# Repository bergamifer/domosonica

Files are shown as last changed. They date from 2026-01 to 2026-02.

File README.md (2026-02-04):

# Domosonica - WiFi Audio Streaming Board

## Project Overview

Domosonica is an experimental sound spatialization project that aims to create an accessible platform for the creation and immersive listening of spatialized audio, offering a multidirectional acoustic experience. Unlike traditional approaches that often involve expensive technologies and are confined to exclusive cultural settings, Domosonica takes an inclusive approach by leveraging recycled or low-cost technological resources.

This repository contains the design files for the WiFi-enabled audio streaming board, the core electronic component of the Domosonica project.

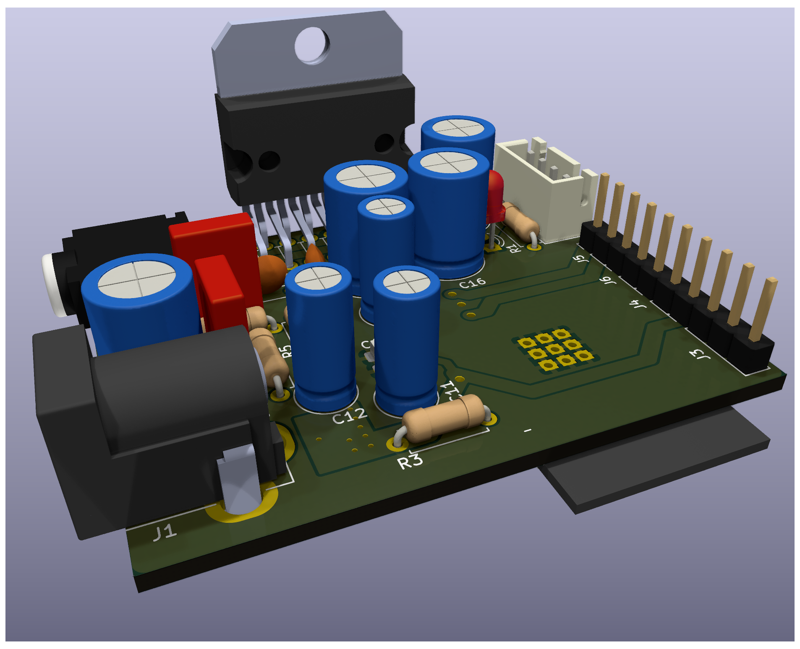
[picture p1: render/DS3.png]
Board Render


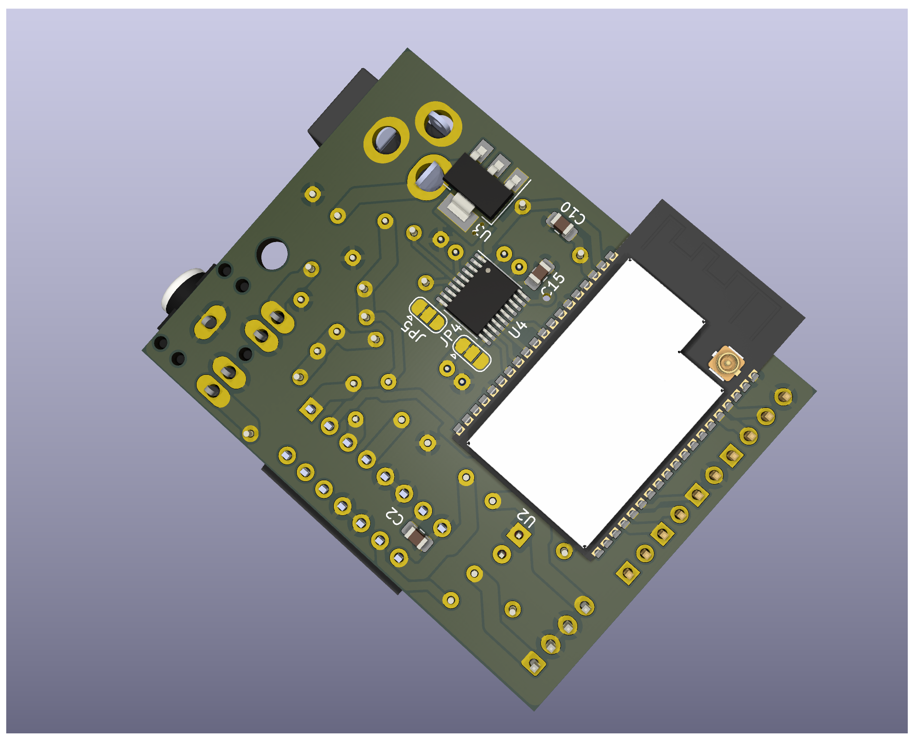
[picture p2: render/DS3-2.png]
Board Render Alternative View


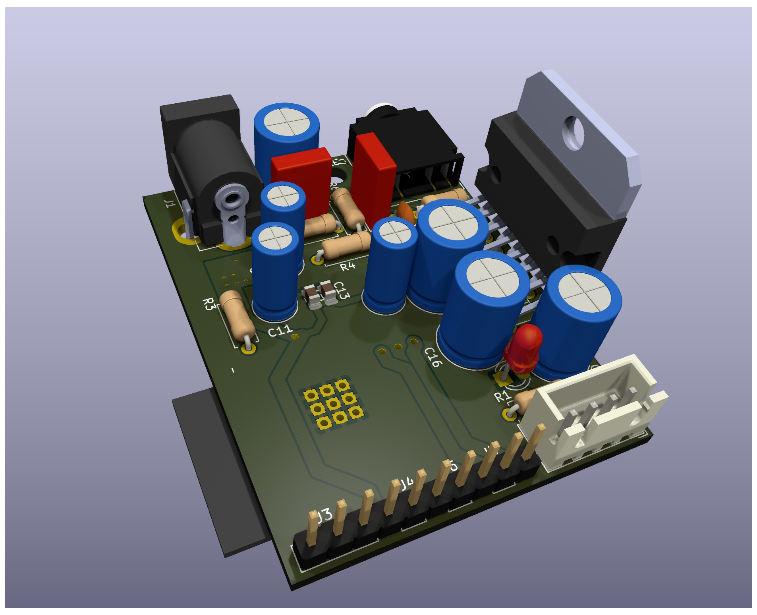
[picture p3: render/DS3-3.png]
Board Render Alternative View


## Key Features

- **Inclusive Access**: Designed to break down barriers, making spatialized audio accessible to a wide range of creators, artists, students, and educators.
- **Community Interaction**: Fosters social connections and collaboration between diverse stakeholders in the arts and the local community.
- **Democratizing Sound Art**: By embracing low-cost and recycled technologies, Domosonica democratizes technological sound art, making it available to a broader audience.
- **Cultural Enrichment**: Contributes significantly to the cultural landscape of Parque de Los Patricios, aligning with the identity of the Technology District of Buenos Aires.

## Technical Specifications

### Hardware Components

1. **ESP32 Microcontroller**: A powerful microcontroller with Wi-Fi and Bluetooth capabilities, serving as the heart of the project. It handles internet connectivity, file storage, and audio output.

2. **TDA7496 Stereo Amplifier**: Each board includes a stereo amplifier capable of driving a pair of speakers directly.

3. **SPIFFS (Serial Peripheral Interface Flash File System)**: An onboard file system used by the ESP32 for storing files, useful for caching audio content.

4. **I2S Digital Audio Interface**: A communication protocol specifically designed for digital audio. The ESP32's I2S interface connects to the internal DAC for audio output.

5. **Recycled Speakers**: The system uses speakers salvaged from old televisions, mounted in custom 3D-printed enclosures.

### Circuitry

- **I2S Pins**: The ESP32 is connected to the DAC using specific pins dedicated to I2S communication. These pins transmit the clock signals and the audio data.
- **Power Supply**: The ESP32 and the audio output devices require a stable power supply. USB power or a regulated power adapter can be used.
- **Stereo Output**: Each board drives two speakers independently for stereo sound reproduction.

### Software Components

- **WiFi Library**: For connecting the ESP32 to the internet via Wi-Fi.
- **HTTPClient Library**: For handling HTTP requests to download audio files.
- **SPIFFS Library**: For interfacing with the ESP32's onboard file system.
- **AudioTools Library**: A comprehensive library for audio playback, including support for various audio formats and protocols, including MP3 decoding and I2S.
- **AudioLibs and AudioCodecs**: Additional libraries that provide specific functionality, such as interfacing with the SPIFFS and decoding audio files.

### Setup and Configuration

- Wi-Fi credentials and target URL for audio streams are specified in the firmware.
- I2S and audio playback settings are configured to match the capabilities of the ESP32 and the connected audio hardware.

### Usage

Once the system is powered and the firmware is running:
1. The ESP32 connects to the specified Wi-Fi network.
2. It receives audio streams from the network.
3. Audio playback occurs automatically using the I2S protocol through the TDA7496 amplifier.

## The Dome Installation

The geodesic dome measures 4 meters in diameter and is suspended from the ceiling of "Circo" at CheLA. The structure is held by 5 attachment points (carabiners), keeping the space below free for visitors to explore its interior from a sonic perspective.

### Speaker Design

30 custom enclosures were designed and 3D printed, each housing a recycled television speaker. These speakers were mounted at the nodes of the geodesic dome structure and connected in pairs to each streaming board.

### Board Manufacturing

The PCB was designed from scratch using KiCad (open-source software). The boards were manufactured in China and then hand-soldered at the Pedalúdico workshop at CheLA.

## Location

**CheLA (Centro Hipermediático Experimental Latinoamericano)** is a cultural center located in Buenos Aires, Argentina. It is known for its focus on experimental and multimedia arts, technology, and cultural activities. CheLA provides a space for artists, creators, and researchers to explore various forms of art and technology.

## Educational Workshops

The project included a series of workshops:

- **Amplifier Building Workshops**: A series of 3 workshops (15 participants each) where young people built amplifiers using recycled TV speakers. Participants took home their own amplifiers to connect to their phones and listen to music.

- **FADU (UBA) Collaborations**: Practical sessions were conducted with design students from the Faculty of Architecture, Design and Urbanism at the University of Buenos Aires.

- **Community Building**: Neighborhood residents from Barracas participated in the construction of the dome, which was assembled using PVC pipes shaped with a heat gun.

## Final Conclusions

### Technical Learnings

The ESP32 microcontroller, while powerful and cost-effective, proved to have limitations when processing large volumes of audio signals simultaneously. The board was designed with only **two stereo channels** per unit, which initially seemed limiting for an immersive audio installation.

### Scaling the Solution

To overcome the channel limitation, we manufactured **20 boards in total**, resulting in **40 independent audio channels** distributed throughout the dome. While achieving perfect synchronization across all WiFi-connected units presented challenges, we managed to obtain sufficient synchronization to create compelling surround sound effects.

### Artistic Results

The system enabled some truly **interesting surround sound experiments** inside the dome. The ability to independently control each speaker pair over the local network opened creative possibilities for spatial audio compositions and performances.

### Future Potential

The dome has significant untapped potential. Our vision is to develop a platform that would allow artists from around the world to simultaneously stream their instruments to each speaker independently, creating a new paradigm for collaborative spatial audio performances.

## Safety Notes

- Ensure the power supply is within the acceptable range for the ESP32 and other components to avoid damage.
- Be cautious with speaker volume to prevent hearing damage.
- Properly insulate all connections to prevent shorts.

## License

Domosonica is an open source project. Feel free to use, modify, and share it within the terms of the license.

## Contributing

We welcome contributions from artists, technologists, educators, and anyone interested in pushing the boundaries of sound art.

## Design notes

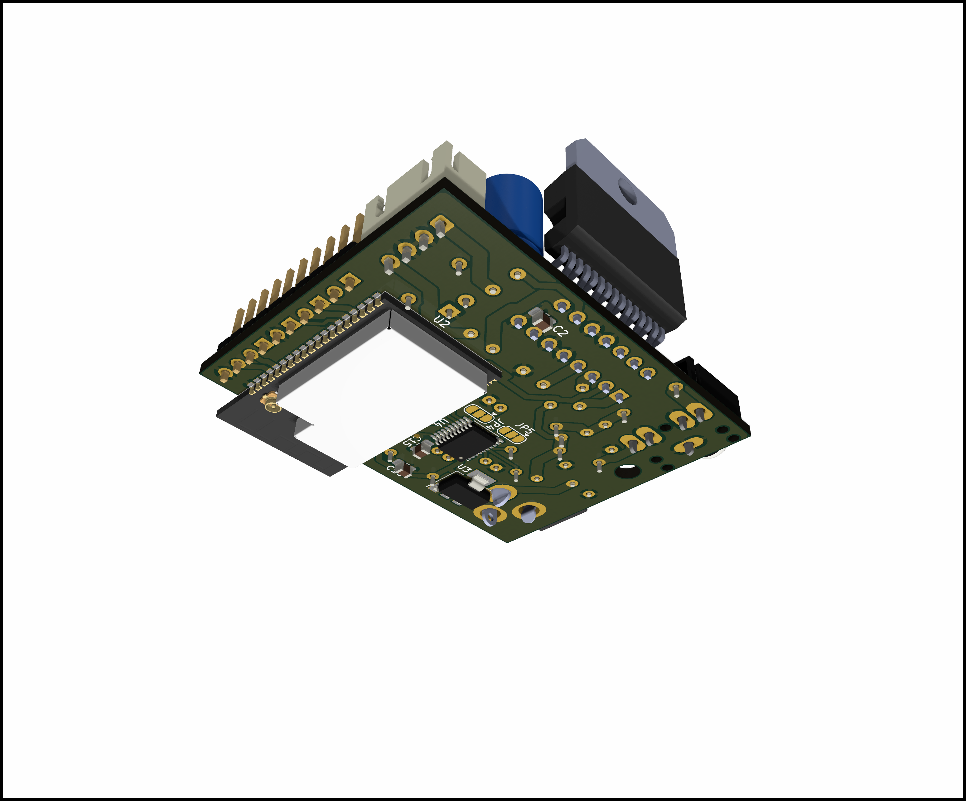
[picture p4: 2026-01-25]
render/Modulo-completo4(2).png

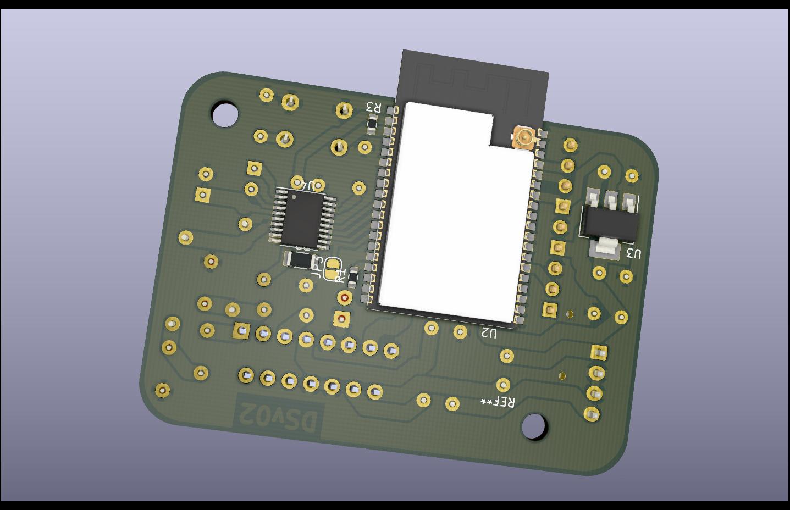
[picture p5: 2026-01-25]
render/Modulo-completo5.jpg

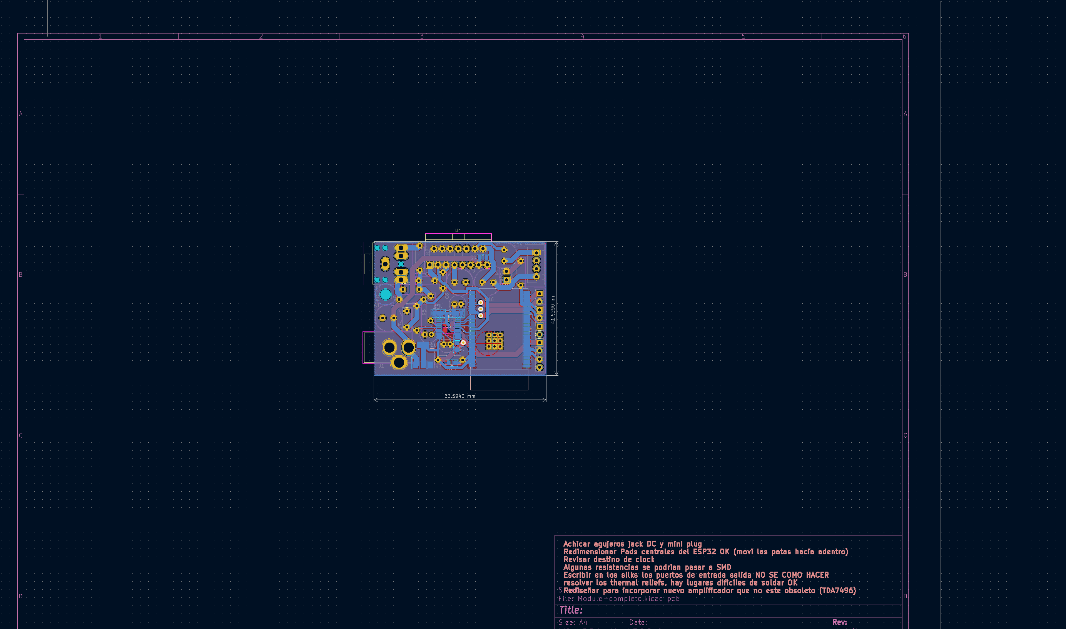
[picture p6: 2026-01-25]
render/Modulo-completo4.png

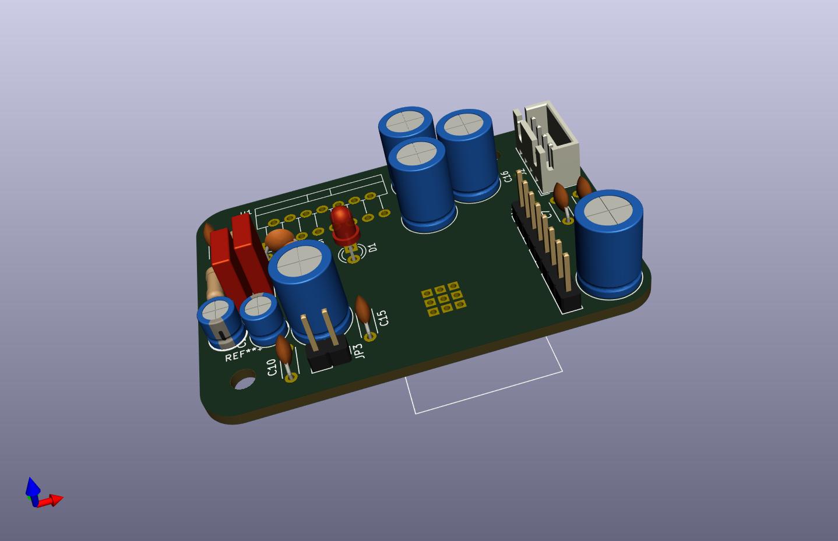
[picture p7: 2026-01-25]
render/Modulo-completo3.jpg

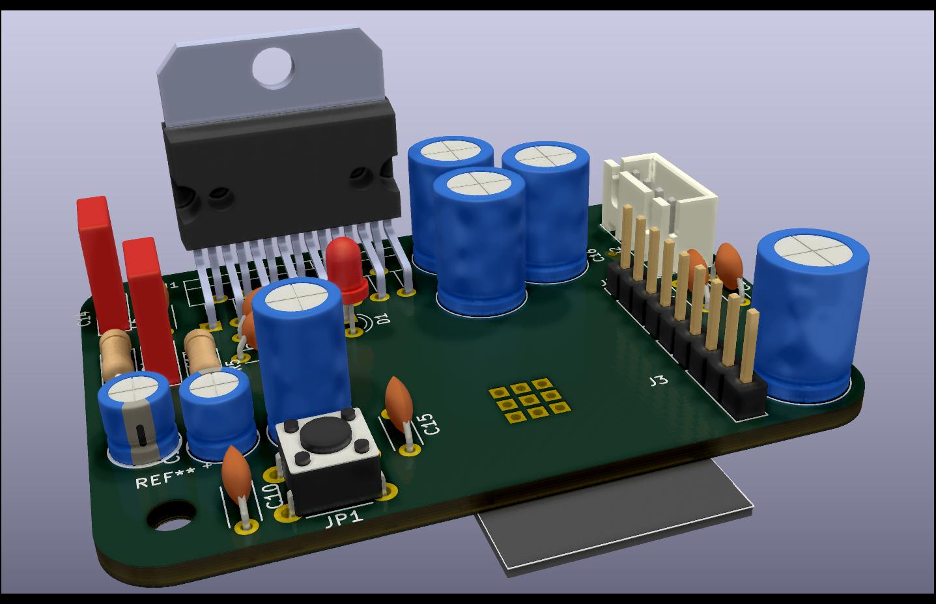
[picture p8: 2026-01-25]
render/Modulo-completo4.jpg

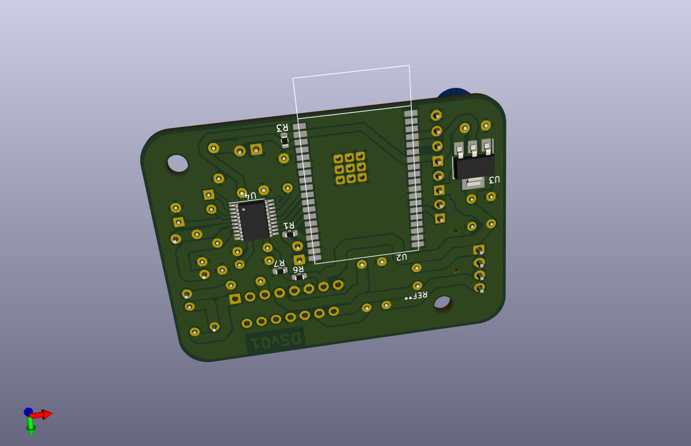
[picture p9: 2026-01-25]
render/Modulo-completo2.jpg

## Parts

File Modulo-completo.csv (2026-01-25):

Reference | Value | Footprint | Datasheet
U3 | AP1117-33 | Package_TO_SOT_SMD:SOT-223-3_TabPin2 | http://www.diodes.com/datasheets/AP1117.pdf
J1 | Conn_01x02 | Connector_PinHeader_2.54mm:PinHeader_1x02_P2.54mm_Vertical | ~
C2 | 100nF | Capacitor_THT:C_Disc_D6.0mm_W2.5mm_P5.00mm | ~
C1 | 1000uF | Capacitor_THT:CP_Radial_D8.0mm_P3.50mm | ~
C8 | 1000uF x 6.3v | Capacitor_THT:CP_Radial_D8.0mm_P3.50mm | ~
J2 | LEFT OUT | Connector_PinHeader_2.54mm:PinHeader_1x02_P2.54mm_Vertical | ~
J4 | RIGHT OUT | Connector_PinHeader_2.54mm:PinHeader_1x02_P2.54mm_Vertical | ~
C7 | 0.1u | Capacitor_THT:C_Disc_D4.3mm_W1.9mm_P5.00mm | ~
R3 | 10k | Resistor_THT:R_Axial_DIN0207_L6.3mm_D2.5mm_P7.62mm_Horizontal | ~
C10 | 0.1u | Capacitor_THT:C_Disc_D4.3mm_W1.9mm_P5.00mm | ~
JP1 | Jumper_NO_Small | Connector_PinHeader_2.54mm:PinHeader_1x02_P2.54mm_Vertical | ~
J3 | Conn_01x04 | Connector_PinHeader_2.54mm:PinHeader_1x04_P2.54mm_Vertical | ~
JP3 | Jumper | Connector_PinHeader_2.54mm:PinHeader_1x02_P2.54mm_Vertical | ~
U2 | ESP32-WROVER_E | esp32-wrover:ESP32-WROVER(EDIT)
U4 | PCM5100 | Package_SO:TSSOP-20_4.4x6.5mm_P0.65mm | http://www.ti.com/lit/ds/symlink/pcm5100.pdf
R5 | 470 | Resistor_THT:R_Axial_DIN0207_L6.3mm_D2.5mm_P10.16mm_Horizontal | ~
C17 | 2.2nF | Capacitor_THT:C_Disc_D4.3mm_W1.9mm_P5.00mm | ~
C11 | 2.2u | Capacitor_THT:CP_Radial_D4.0mm_P1.50mm | ~
R4 | 470 | Resistor_THT:R_Axial_DIN0207_L6.3mm_D2.5mm_P10.16mm_Horizontal | ~
C12 | 2.2u | Capacitor_THT:CP_Radial_D4.0mm_P1.50mm | ~
C13 | 0.1u | Capacitor_THT:C_Disc_D4.3mm_W1.9mm_P5.00mm | ~
C14 | 2.2nF | Capacitor_THT:C_Disc_D4.3mm_W1.9mm_P5.00mm | ~
C15 | 0.1u | Capacitor_THT:C_Disc_D4.3mm_W1.9mm_P5.00mm | ~
R6 | 1K5 | Resistor_THT:R_Axial_DIN0207_L6.3mm_D2.5mm_P10.16mm_Horizontal | ~
R7 | 500 | Resistor_THT:R_Axial_DIN0207_L6.3mm_D2.5mm_P10.16mm_Horizontal | ~
C18 | 100nF | Capacitor_THT:C_Disc_D4.3mm_W1.9mm_P5.00mm | ~
JP2 | Jumper | Jumper:SolderJumper-2_P1.3mm_Open_TrianglePad1.0x1.5mm | ~
C5 | 0.47uF | Capacitor_THT:C_Rect_L11.5mm_W4.3mm_P10.00mm_MKT | ~
C6 | 0.47uF | Capacitor_THT:C_Rect_L11.5mm_W4.3mm_P10.00mm_MKT | ~
U1 | TDA7496 | Package_TO_SOT_THT:TO-220-15_P2.54x2.54mm_StaggerOdd_Lead4.58mm_Vertical | http://www.st.com/resource/en/datasheet/tda7297.pdf
C9 | 470uF | Capacitor_THT:CP_Radial_D8.0mm_P3.80mm | ~
C16 | 470uF | Capacitor_THT:CP_Radial_D8.0mm_P3.80mm | ~
C19 | 470uF | Capacitor_THT:CP_Radial_D8.0mm_P3.80mm | ~

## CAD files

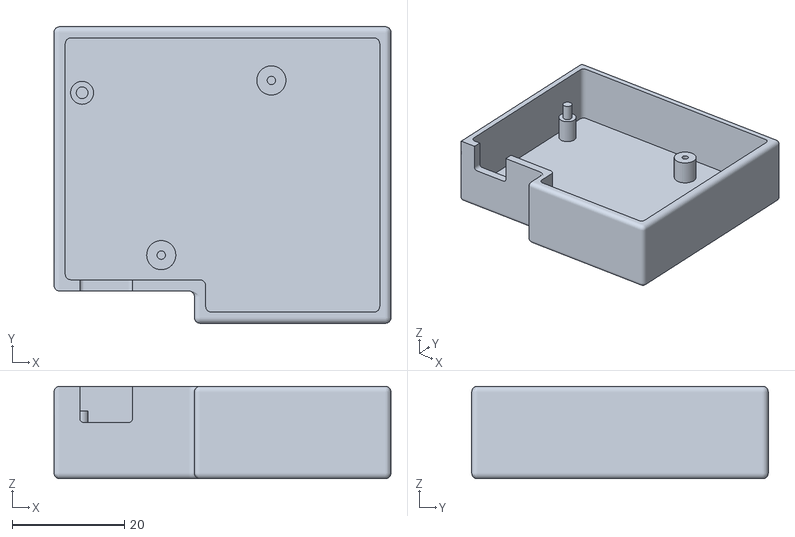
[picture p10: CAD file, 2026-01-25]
case/case-domo.stl
60.0 x 52.8 x 16.4

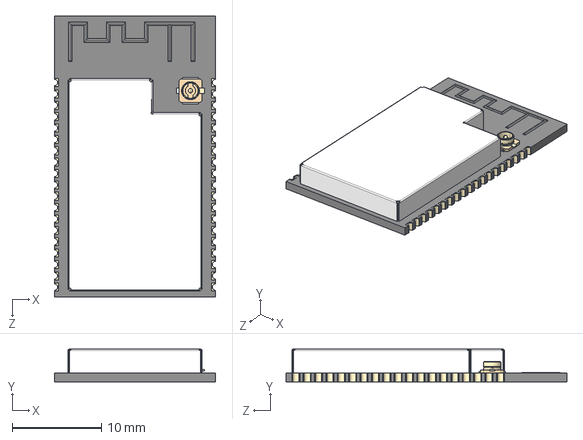
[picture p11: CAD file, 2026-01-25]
librerias/ESP32-WROVER-I--3DModel-STEP-56544.STEP
18.0 x 3.65 x 31.4 mm

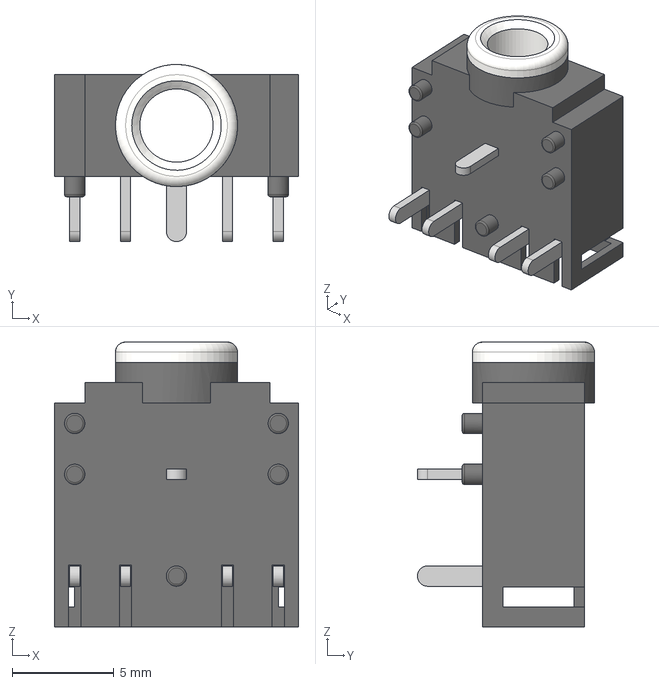
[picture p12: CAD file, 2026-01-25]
librerias/pj-307-stereo-connector-1.snapshot.5/pj-307.step
12.0 x 8.70 x 14.0 mm

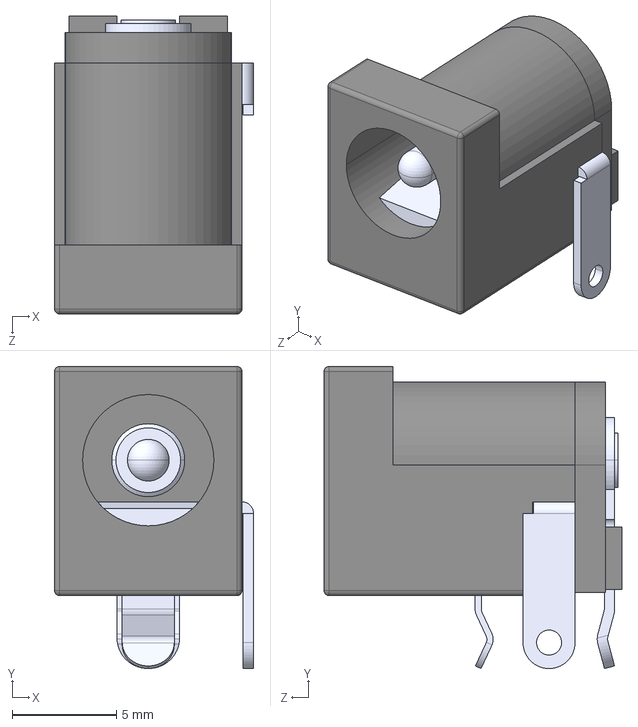
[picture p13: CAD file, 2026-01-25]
librerias/DCJ200-10-A-K1-K--3DModel-STEP-56544.STEP
9.55 x 14.5 x 14.3 mm

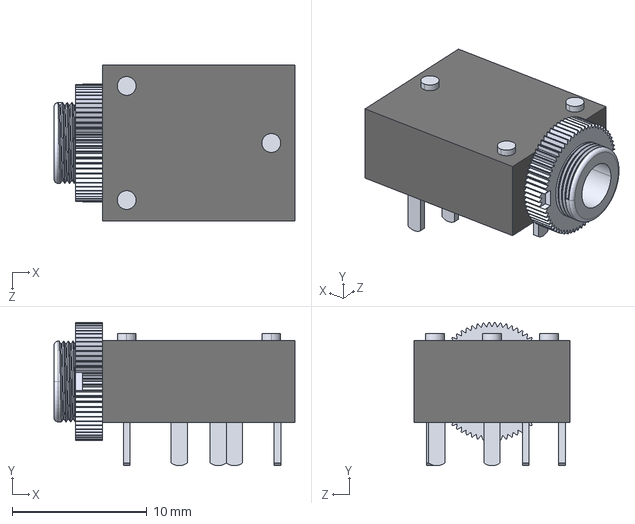
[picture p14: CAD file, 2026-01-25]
librerias/KB3SPRS.STEP
17.9 x 10.6 x 11.6 mm

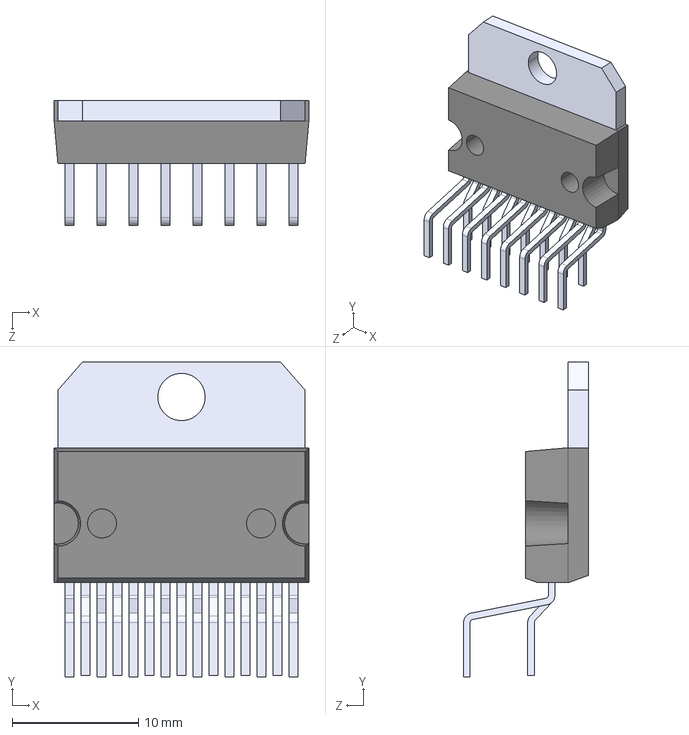
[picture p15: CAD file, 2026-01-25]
librerias/L296.STEP
20.2 x 25.0 x 9.89 mm

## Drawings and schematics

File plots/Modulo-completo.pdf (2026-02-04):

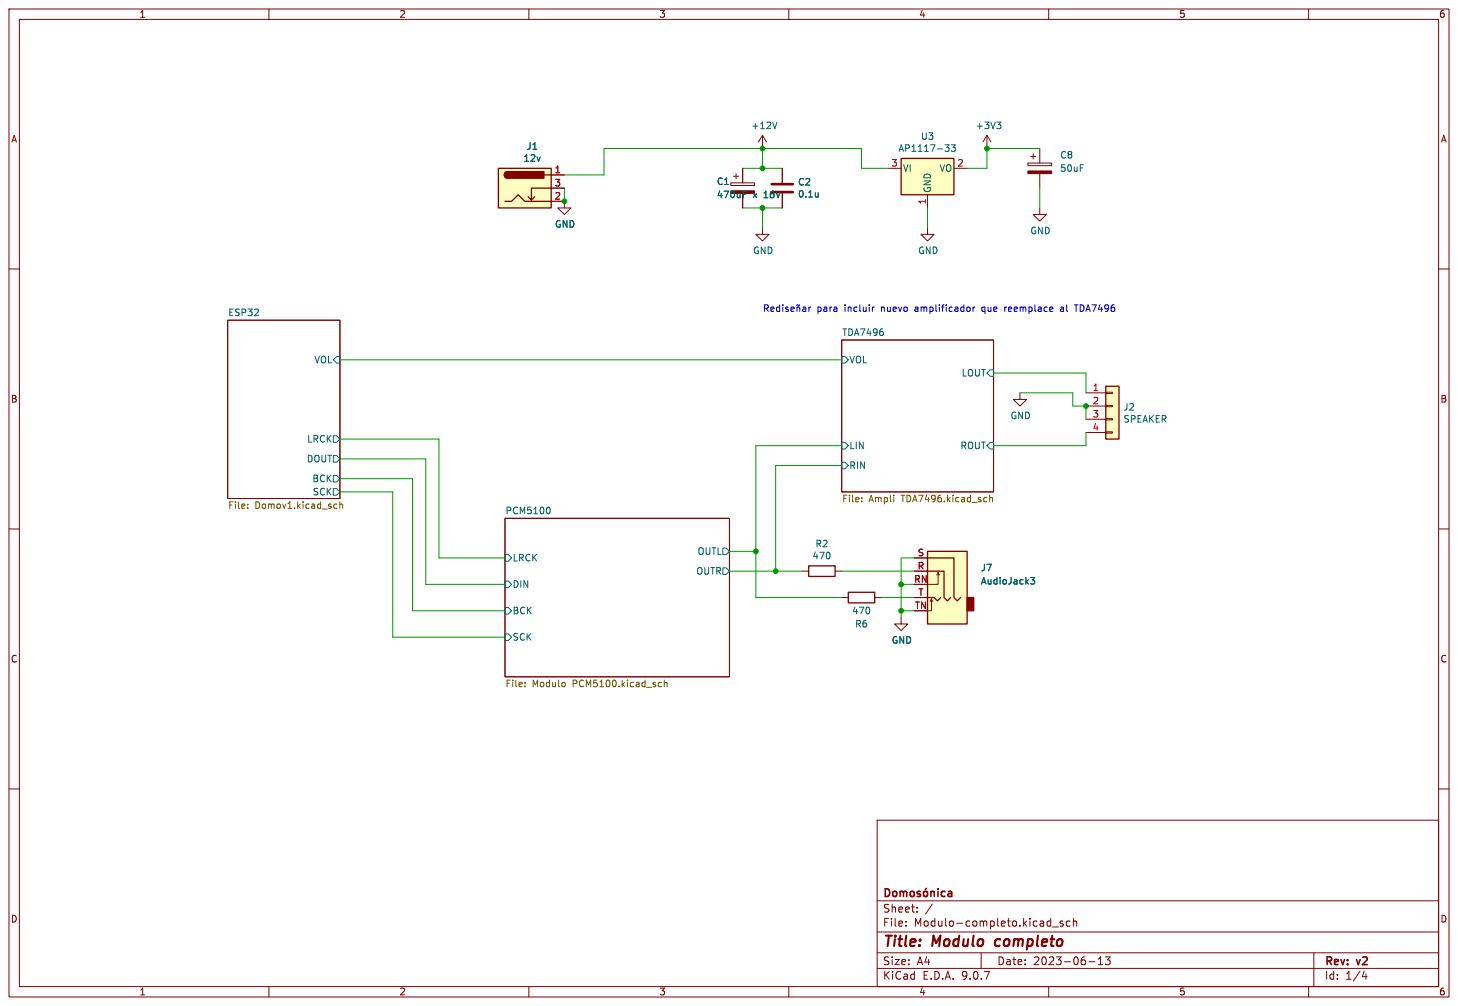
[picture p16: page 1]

LRCK
PCM5100 File: Modulo PCM5100.kicad_sch DOUT BCK

File: Modulo-completo.kicad_sch Sheet: / þÿDomosónica OUTL OUTR

Id: 1/4 Title: Modulo completo

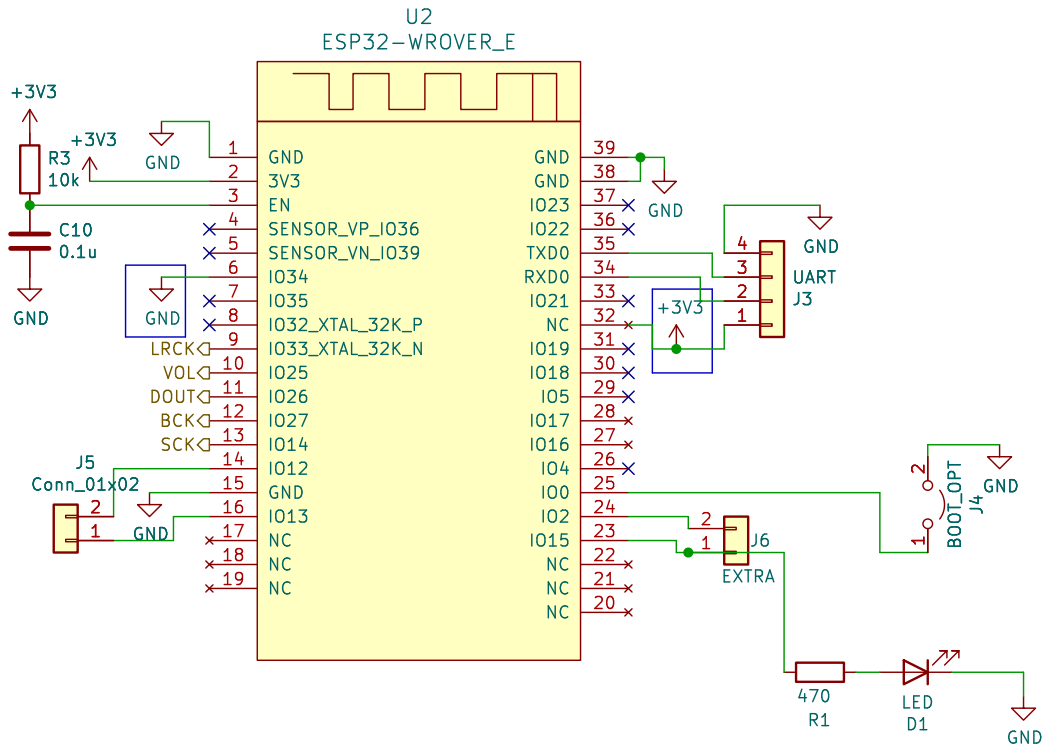
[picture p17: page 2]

Id: 2/4 Title: Modulo completo

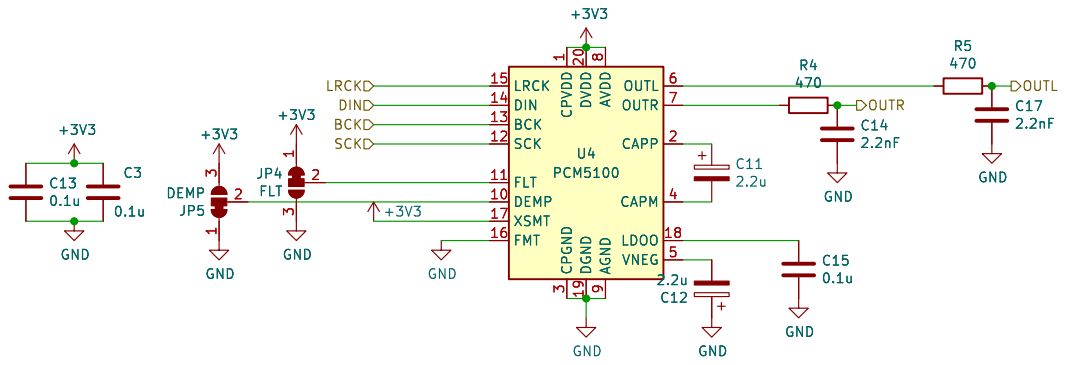
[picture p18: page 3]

9 OUTL 6 OUTR 7 CAPP 2 CAPM 4

Id: 3/4 Title: Modulo completo

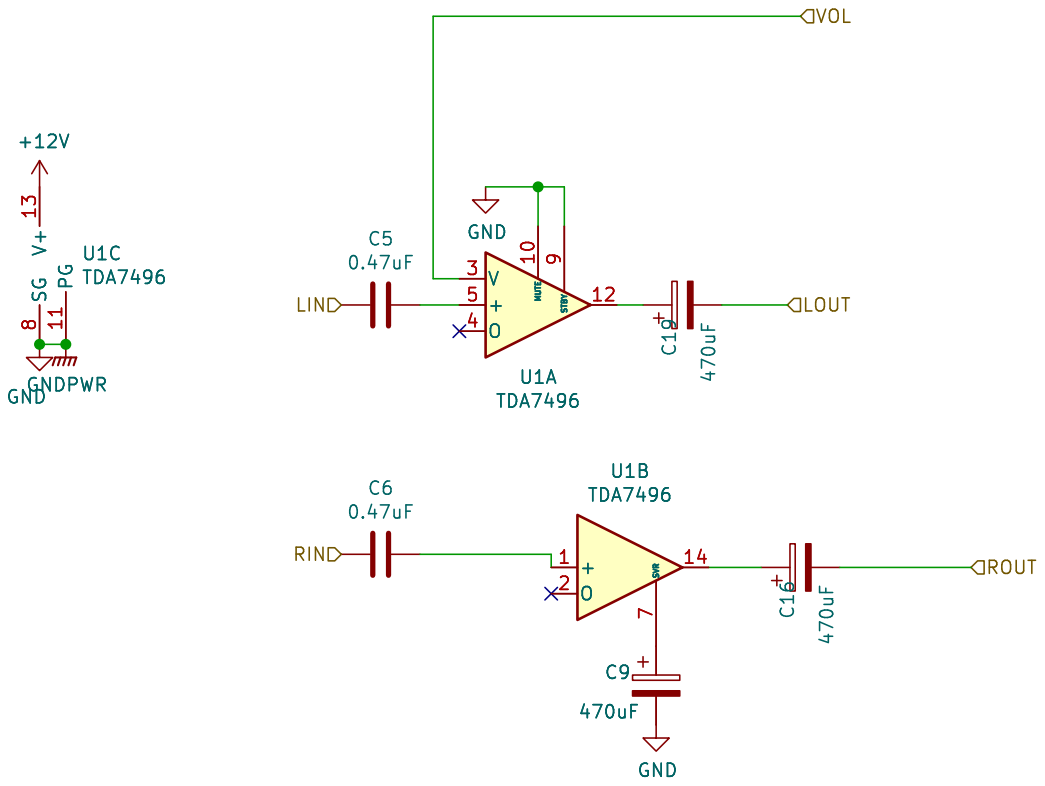
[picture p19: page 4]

LOUT VOL GNDPWR GND
TDA7496 GND GND
0.47uF RIN

File: Ampli TDA7496.kicad_sch Sheet: /TDA7496/ þÿDomosónica GNDPWR GNDV+ 13 SG

Id: 4/4 Title: Modulo completo

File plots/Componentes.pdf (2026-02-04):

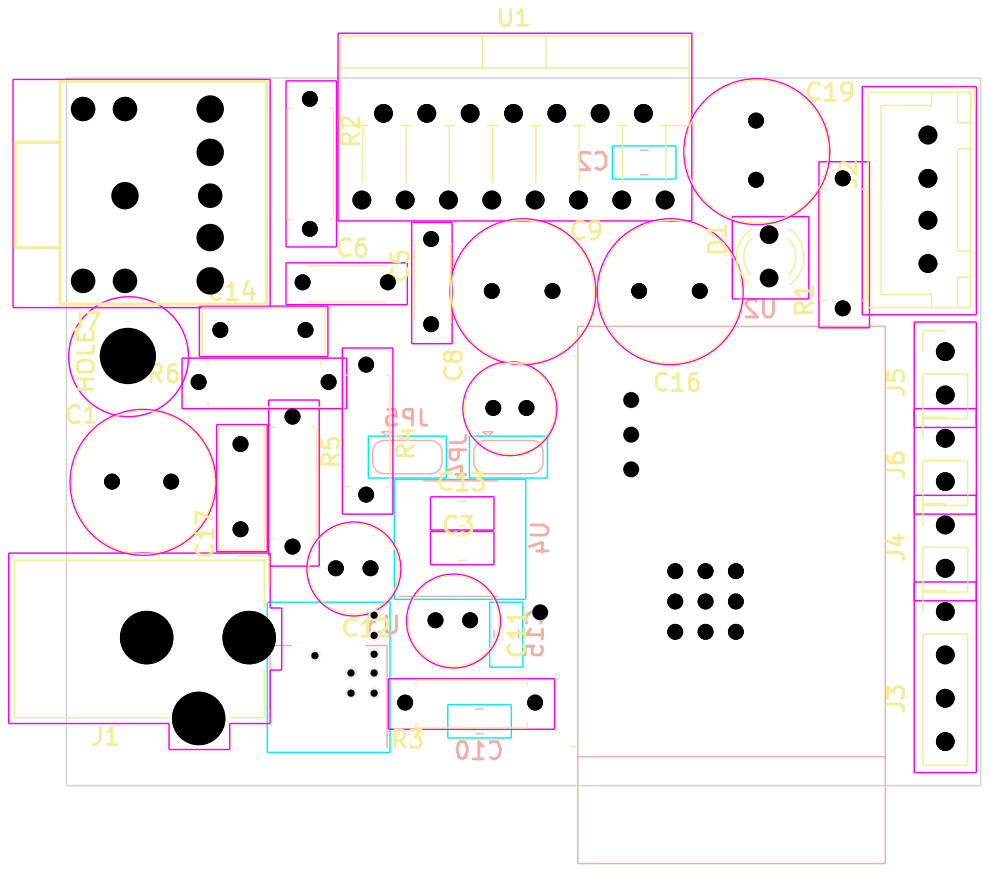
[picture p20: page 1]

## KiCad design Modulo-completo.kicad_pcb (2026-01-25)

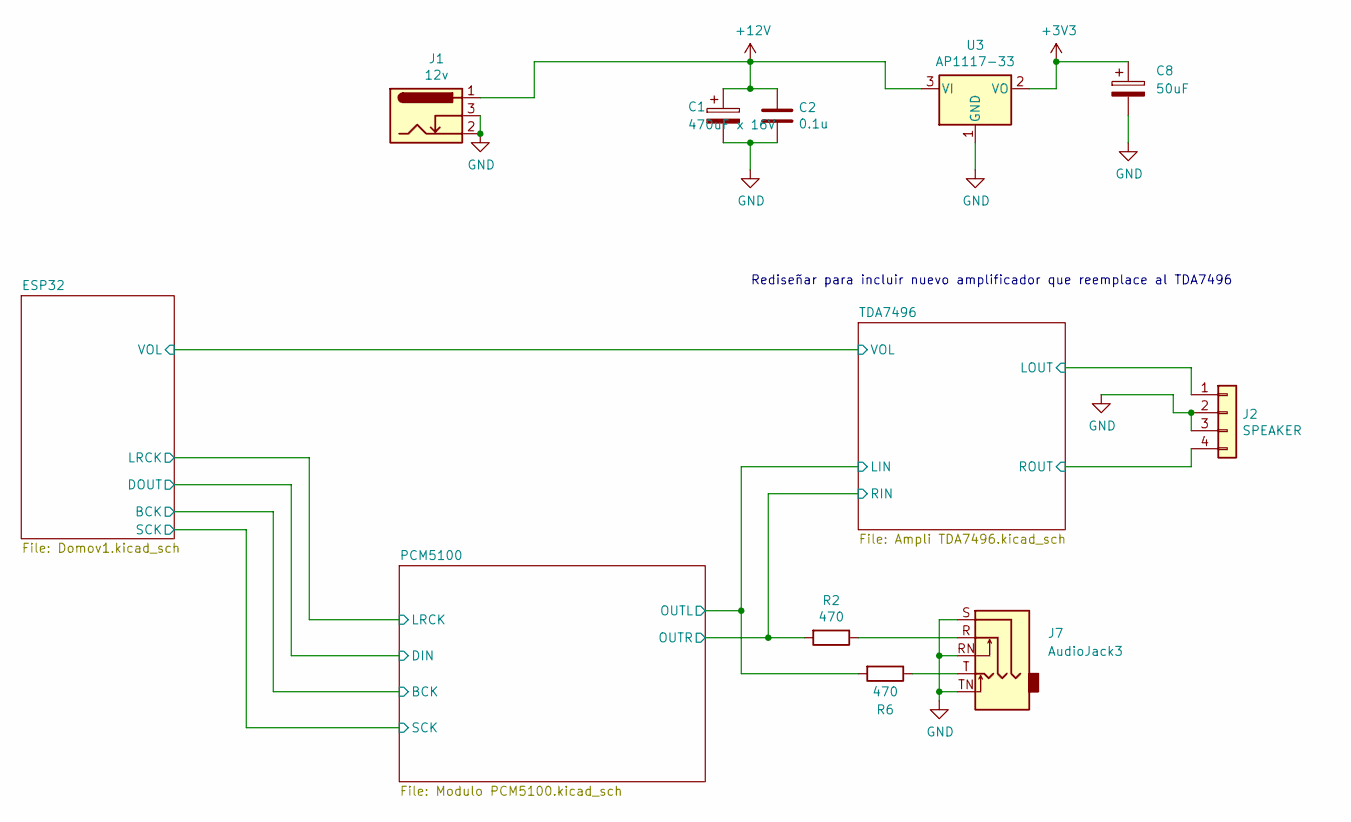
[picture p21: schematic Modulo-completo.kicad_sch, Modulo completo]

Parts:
C1: 470uF x 16V; C_Radial_D8.0mm_H11.5mm_P3.50mm
C2: 0.1u; C_0805_2012Metric_Pad1.18x1.45mm_HandSolder
C8: 50uF; C_Radial_D5.0mm_H11.0mm_P2.00mm
J1: 12v; BarrelJack_CUI_PJ-102AH_Horizontal
J2: SPEAKER; JST_XH_B4B-XH-A_1x04_P2.50mm_Vertical
J7: AudioJack3; Jack_3.5mm_Tayda
R2, R6: 470; R_Axial_DIN0207_L6.3mm_D2.5mm_P7.62mm_Horizontal
U3: AP1117-33; SOT-223-3_TabPin2

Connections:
+3V3: C8.1, U3.2 (VO); also elsewhere on the board
+12V: C1.1, C2.1, J1.1, U3.3 (VI); also elsewhere on the board
/PCM5100/OUTL: R6.2; also elsewhere on the board
/PCM5100/OUTR: R2.2; also elsewhere on the board
/TDA7496/LOUT: J2.1; also elsewhere on the board
/TDA7496/ROUT: J2.4; also elsewhere on the board
GND: C1.2, C2.2, C8.2, J1.2, J1.3, J2.2, J2.3, J7.RN, J7.S, J7.TN, U3.1 (GND); also elsewhere on the board
unnamed: J7.R, R2.1
unnamed: J7.T, R6.1

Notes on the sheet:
Rediseñar para incluir nuevo amplificador que reemplace al TDA7496

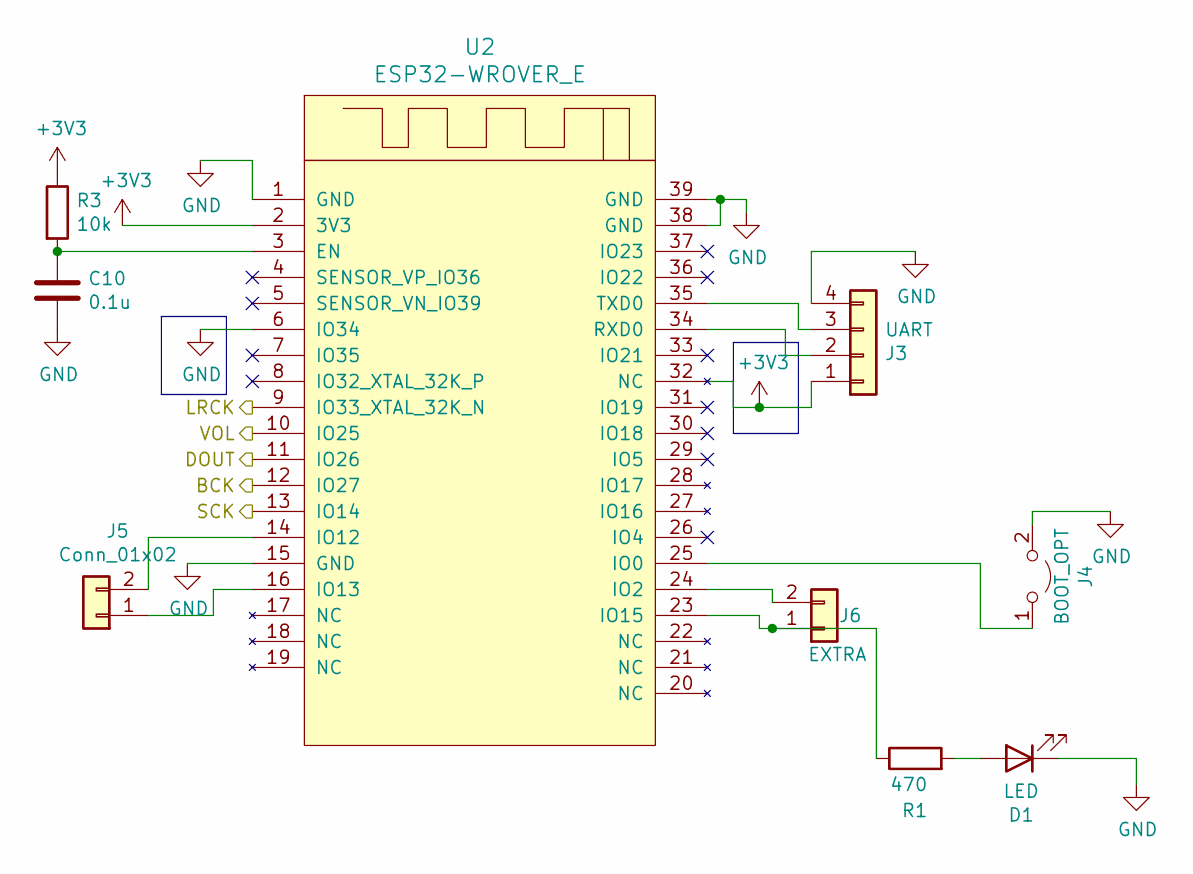
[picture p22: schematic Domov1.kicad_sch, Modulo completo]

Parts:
C10: 0.1u; C_0805_2012Metric_Pad1.18x1.45mm_HandSolder
D1: LED; LED_D3.0mm
J3: UART; PinHeader_1x04_P2.54mm_Vertical
J4: BOOT_OPT; PinHeader_1x02_P2.54mm_Vertical
J5: Conn_01x02; PinHeader_1x02_P2.54mm_Vertical
J6: EXTRA; PinHeader_1x02_P2.54mm_Vertical
R1: 470; R_Axial_DIN0207_L6.3mm_D2.5mm_P7.62mm_Horizontal
R3: 10k; R_Axial_DIN0207_L6.3mm_D2.5mm_P7.62mm_Horizontal
U2: ESP32-WROVER_E; ESP32-WROVER(EDIT)

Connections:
+3V3: J3.1, R3.1, U2.2 (3V3), U2.32 (NC); also elsewhere on the board
/ESP32/BCK: U2.12 (IO27); also elsewhere on the board
/ESP32/DOUT: U2.11 (IO26); also elsewhere on the board
/ESP32/LRCK: U2.9 (IO33_XTAL_32K_N); also elsewhere on the board
/ESP32/SCK: U2.13 (IO14); also elsewhere on the board
/ESP32/VOL: U2.10 (IO25); also elsewhere on the board
GND: C10.2, D1.1 (K), J3.4, J4.2 (B), U2.1 (GND), U2.6 (IO34), U2.15 (GND), U2.38 (GND), U2.39 (GND); also elsewhere on the board
unnamed: C10.1, R3.2, U2.3 (EN)
unnamed: D1.2 (A), R1.2
unnamed: J3.2, U2.34 (RXD0)
unnamed: J3.3, U2.35 (TXD0)
unnamed: J4.1 (A), U2.25 (IO0)
unnamed: J5.1, U2.16 (IO13)
unnamed: J5.2, U2.14 (IO12)
unnamed: J6.1, R1.1, U2.23 (IO15)
unnamed: J6.2, U2.24 (IO2)

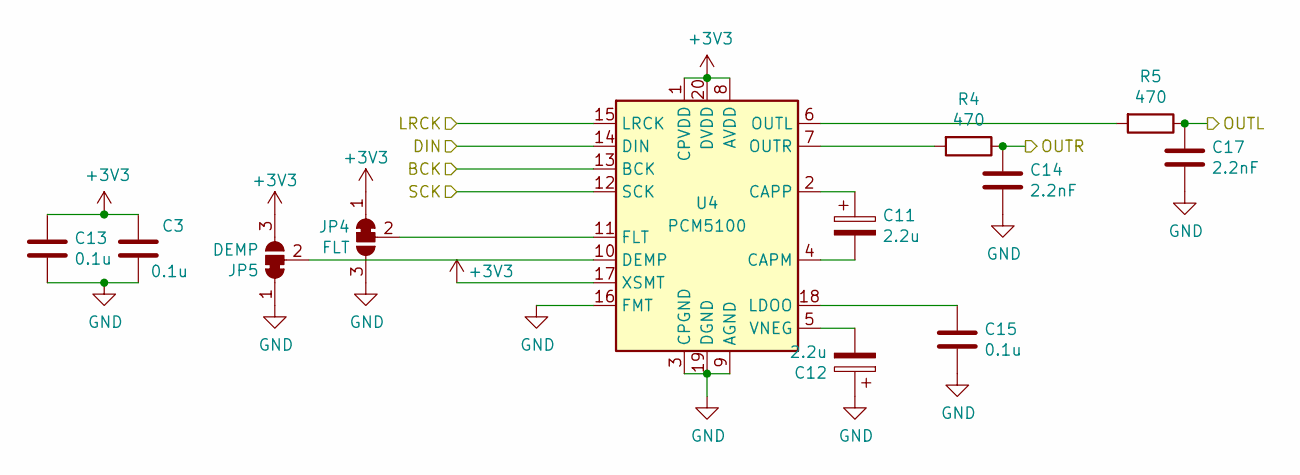
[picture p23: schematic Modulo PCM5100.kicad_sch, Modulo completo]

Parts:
C3, C13, C15: 0.1u; C_0805_2012Metric_Pad1.18x1.45mm_HandSolder
C11, C12: 2.2u; C_Radial_D5.0mm_H11.0mm_P2.00mm
C14, C17: 2.2nF; C_Rect_L7.0mm_W2.5mm_P5.00mm
JP4: FLT; SolderJumper-3_P1.3mm_Bridged12_RoundedPad1.0x1.5mm
JP5: DEMP; SolderJumper-3_P1.3mm_Bridged12_RoundedPad1.0x1.5mm
R4, R5: 470; R_Axial_DIN0207_L6.3mm_D2.5mm_P7.62mm_Horizontal
U4: PCM5100; TSSOP-20_4.4x6.5mm_P0.65mm

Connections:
+3V3: C3.1, C13.1, JP4.1 (A), JP5.3 (B), U4.1 (CPVDD), U4.8 (AVDD), U4.17 (XSMT), U4.20 (DVDD); also elsewhere on the board
/ESP32/BCK: U4.13 (BCK); also elsewhere on the board
/ESP32/DOUT: U4.14 (DIN); also elsewhere on the board
/ESP32/LRCK: U4.15 (LRCK); also elsewhere on the board
/ESP32/SCK: U4.12 (SCK); also elsewhere on the board
/PCM5100/OUTL: C17.1, R5.1; also elsewhere on the board
/PCM5100/OUTR: C14.1, R4.1; also elsewhere on the board
GND: C3.2, C12.1, C13.2, C14.2, C15.2, C17.2, JP4.3 (B), JP5.1 (A), U4.3 (CPGND), U4.9 (AGND), U4.16 (FMT), U4.19 (DGND); also elsewhere on the board
unnamed: C11.1, U4.2 (CAPP)
unnamed: C11.2, U4.4 (CAPM)
unnamed: C12.2, U4.5 (VNEG)
unnamed: C15.1, U4.18 (LDOO)
unnamed: JP4.2 (C), U4.11 (FLT)
unnamed: JP5.2 (C), U4.10 (DEMP)
unnamed: R4.2, U4.7 (OUTR)
unnamed: R5.2, U4.6 (OUTL)

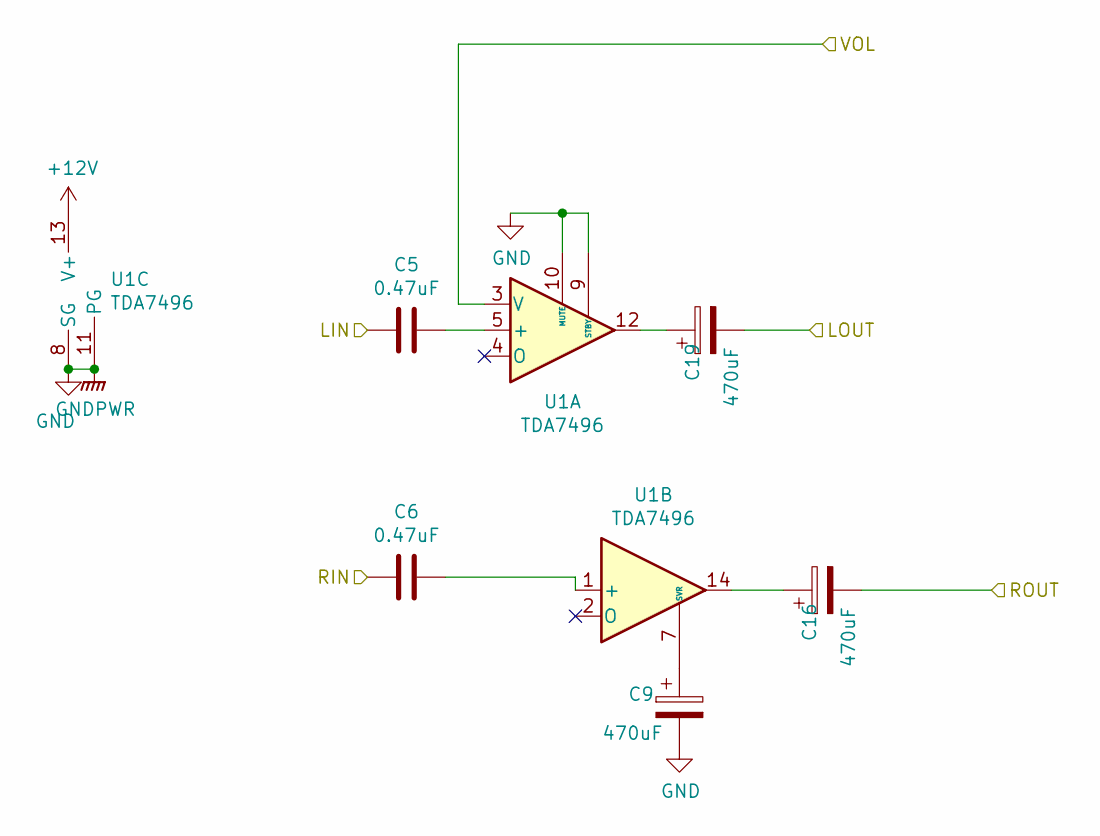
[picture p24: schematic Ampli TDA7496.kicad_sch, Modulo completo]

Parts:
C5, C6: 0.47uF; C_Disc_D4.3mm_W1.9mm_P5.00mm
C9, C16, C19: 470uF; C_Radial_D8.0mm_H11.5mm_P3.50mm
U1: TDA7496; TO-220-15_P2.54x2.54mm_StaggerOdd_Lead4.58mm_Vertical

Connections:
+12V: U1.13 (V+); also elsewhere on the board
/ESP32/VOL: U1.3 (V); also elsewhere on the board
/PCM5100/OUTL: C5.2; also elsewhere on the board
/PCM5100/OUTR: C6.2; also elsewhere on the board
/TDA7496/LOUT: C19.2; also elsewhere on the board
/TDA7496/ROUT: C16.2; also elsewhere on the board
GND: C9.2, U1.8 (SG), U1.9 (STBY), U1.10 (MUTE), U1.11 (PG), U1.15 (PG); also elsewhere on the board
unnamed: C5.1, U1.5 (+)
unnamed: C6.1, U1.1 (+)
unnamed: C9.1, U1.7 (SVR)
unnamed: C16.1, U1.14
unnamed: C19.1, U1.12

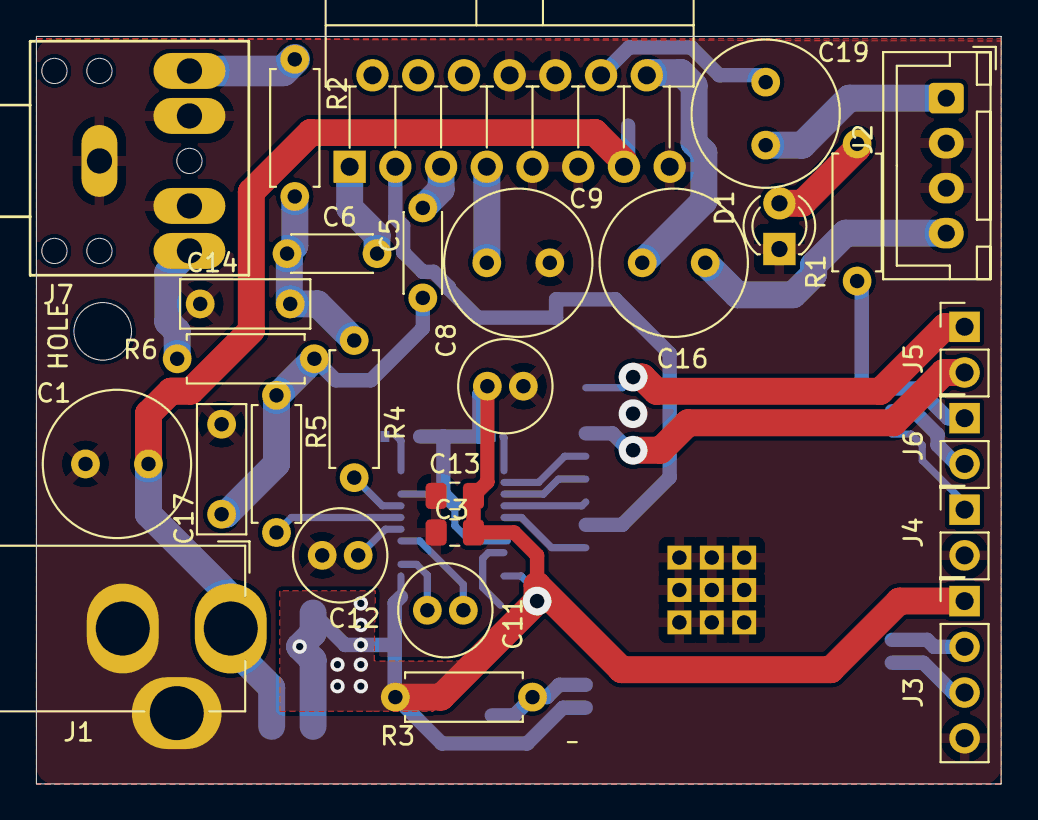
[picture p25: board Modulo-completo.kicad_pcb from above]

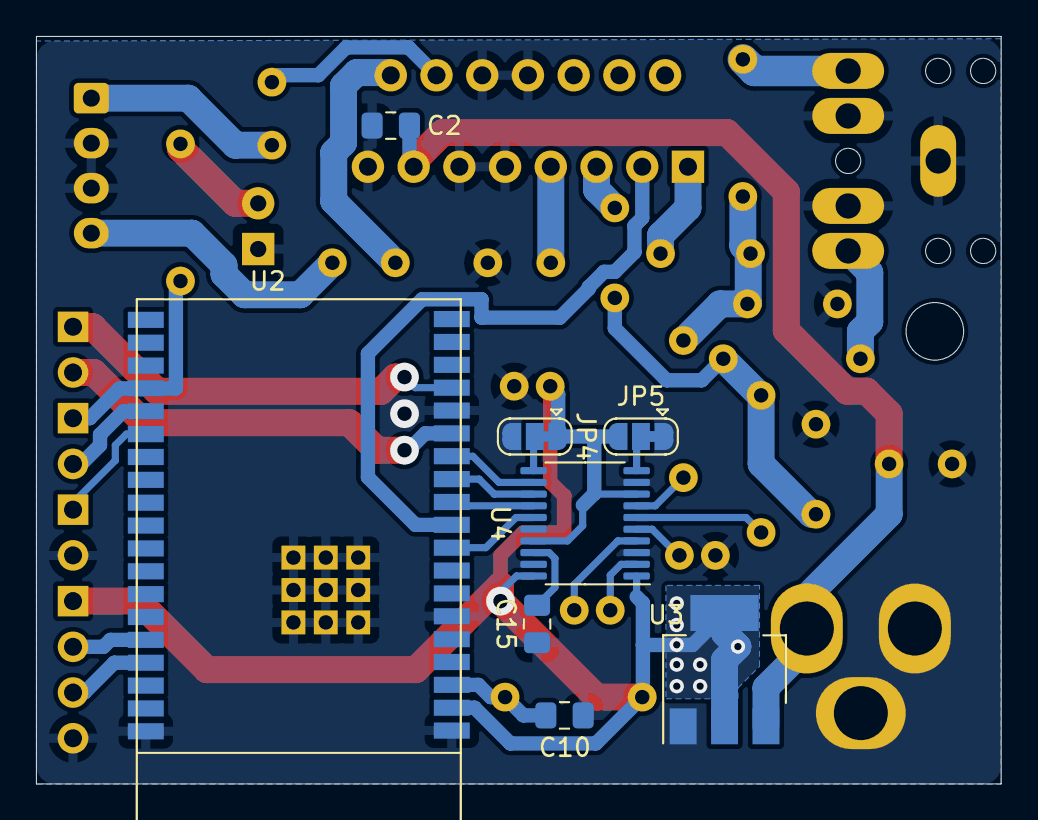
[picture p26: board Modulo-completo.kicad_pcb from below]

Board: 2 copper layers, 53.6 x 41.5 mm, 37 parts (8 on the bottom side), 36 nets.

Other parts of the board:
HOLE: MH; MountingHole_3.2mm_M3

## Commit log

2026-01-25 Version final
    [Ampli TDA7496.kicad_sch, Ampli TDA7496.sch, DCJ200-10-A-K1-K--3DModel-STEP-56544.STEP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]
2026-01-25 Add .gitignore file for KiCad project
2026-01-25 Remove obsolete Gerber files and schematics; add new PNG render of the project.
    [Modulo-completo-B_Cu.gbl, Modulo-completo-B_Cu.gbr, Modulo-completo-B_Mask.gbr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]
2026-01-25 Update board render image format from PNG to JPG in README.md
